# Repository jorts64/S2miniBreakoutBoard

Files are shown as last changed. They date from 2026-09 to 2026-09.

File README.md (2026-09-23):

# S2miniBreakoutBoard
Breakout Board for Lolin S2 mini from wemos.cc

You can 3D print [this STL](STL/soldarS2miniBreakout.stl) for easy soldering. 

I2C slave firmware included with examples of master code in Arduino and micropython

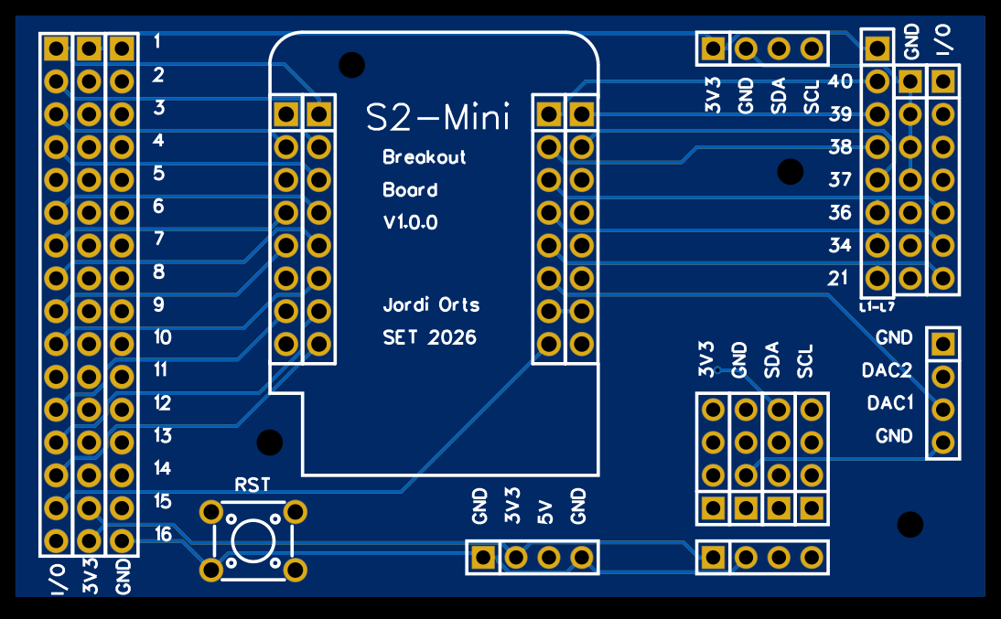
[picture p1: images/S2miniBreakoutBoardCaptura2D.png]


* Easy access to all exposed pins of the S2 mini
* I2C bus connector

## Standalone mode

You can use this PCB as a S2-mini breakout for development or project core. Some [micropython examples](standalone/micropython) included.

In this mode you can put a 7xLED VCC COM module for easy development. Or a 8xLED module (with one pin in the air) as shown in picture:

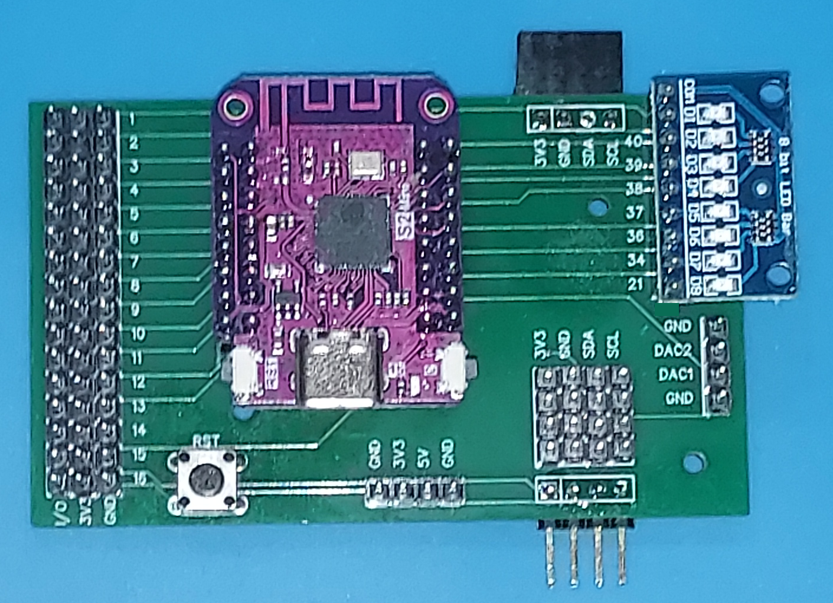
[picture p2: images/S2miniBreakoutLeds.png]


## Slave mode

* Arduino firmware. [Micropython](I2Cslave/master/micropython/ejemplo.py) and [Arduino](https://github.com/jorts64/S2MiniSlave/blob/main/examples/Basic/Basic.ino) master examples avalaible.
* [Arduino library](https://github.com/jorts64/S2MiniSlave)
* 16 I/O you can set individually as INPUT, INPUT_PULLUP, OUTPUT, PWM or ADC
* 2 DAC outputs
* I2C address by jumper configuration, you can choose any I2C address. You can chain up to 128 S2 mini I2C slave devices, if you ignore protocol restrictions [i2c address list: the 0x00–0x77 map](https://i2c.net/i2c-addresses/), so you could get 2048 configurable GPIO and 256 DAC inputs !!
* Really cheap device, about $10 S2 mini included. You can order PCB from JLCPCB and buy electronic components at Aliexpress.

In this mode you must set I2C address with jumpers to GND (active LOW) in pins 21, 34, 36, 37, 38, 39 & 40 (MSB...LSB). The slave in picture has I2C address 0x60:

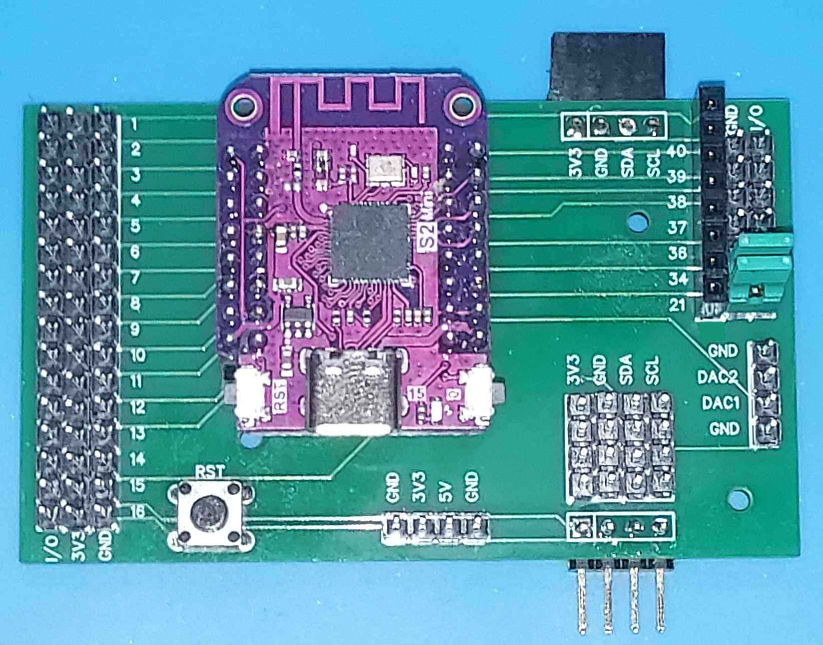
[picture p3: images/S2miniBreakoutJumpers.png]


Female and Male right angle connectors at the top and bottom of the PCB lets chain our S2 mini slaves in the I2C bus.

## Hardware restricctions

As this board uses S2 mini microcontroller:

* DAC2 will give you error voltages because it's connected internally with a 10k pullup. You can improve the output with a R load [ESP32-S2 DAC2 Requires Load Resistor? ](https://github.com/espressif/arduino-esp32/issues/9324?utm_source=chatgpt.com)
* PWM are limited to 8 GPIO.
* ADC witn GPIO15 will give bad results. This GPIO is internally connected to the LED builtiin.
* ADC 11-16 don't be avalaible if WiFi is enabled. Neither DAC1 and DAC2. But they still can be used as INPUT, INPUT_PULLUP, OUTPUT or PWM with WiFi enabled.

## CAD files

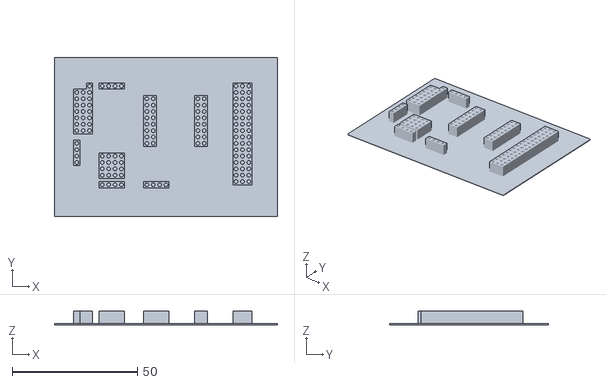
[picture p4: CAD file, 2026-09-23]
STL/soldarS2miniBreakout.stl
88.9 x 63.5 x 5.60

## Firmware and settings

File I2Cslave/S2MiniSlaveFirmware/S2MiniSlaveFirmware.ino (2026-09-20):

#include <Arduino.h>
#include <Wire.h>

// ============================================================
// S2 Mini I2C Slave
// ============================================================
//
// ESP32-S2 / LOLIN S2 Mini
//
// I2C:
//   SDA = GPIO33
//   SCL = GPIO35
//
// Address:
//   GPIO21 = bit 6 (MSB)
//   GPIO34 = bit 5
//   GPIO36 = bit 4
//   GPIO37 = bit 3
//   GPIO38 = bit 2
//   GPIO39 = bit 1
//   GPIO40 = bit 0 (LSB)
//
// GPIO 1..16:
//   INPUT
//   INPUT_PULLUP
//   OUTPUT
//   PWM
//   ADC
//
// DAC:
//   DAC1 = GPIO17
//   DAC2 = GPIO18
//
// ============================================================


// ------------------------------------------------------------
// I2C
// ------------------------------------------------------------

#define I2C_SDA_PIN       33
#define I2C_SCL_PIN       35

// ------------------------------------------------------------
// Address configuration pins
// ------------------------------------------------------------

#define ADDR_BIT6_PIN     21
#define ADDR_BIT5_PIN     34
#define ADDR_BIT4_PIN     36
#define ADDR_BIT3_PIN     37
#define ADDR_BIT2_PIN     38
#define ADDR_BIT1_PIN     39
#define ADDR_BIT0_PIN     40

// ------------------------------------------------------------
// Controlled GPIOs
// ------------------------------------------------------------

#define FIRST_IO          1
#define LAST_IO           16
#define NUM_IO            16

// ------------------------------------------------------------
// DAC
// ------------------------------------------------------------

#define DAC1_PIN          17
#define DAC2_PIN          18

// ------------------------------------------------------------
// PWM
//
// ESP32-S2 has 8 LEDC channels.
// 12-bit PWM is used internally.
//
// The register exposed to the master is 16-bit:
//   0     = 0%
//   65535 = 100%
//
// It is converted to the 12-bit hardware range.
// ------------------------------------------------------------

#define PWM_FREQUENCY     5000
#define PWM_RESOLUTION    12
#define PWM_MAX           ((1UL << PWM_RESOLUTION) - 1)

// ESP32-S2 dispone de 8 canales LEDC
#define MAX_PWM_CHANNELS  8

// Número de GPIO que actualmente utilizan PWM
uint8_t activePWMChannels = 0;

// Estado de cada GPIO
bool pwmAttached[NUM_IO];

// ------------------------------------------------------------
// Protocol
// ------------------------------------------------------------

#define PROTOCOL_VERSION  1

#define REG_VERSION       0x00
#define REG_ADDRESS       0x01
#define REG_PWM_CHANNELS  0x02

#define REG_INPUTS        0x10
#define REG_OUTPUTS       0x12

#define REG_MODE_BASE     0x20
#define REG_PWM_BASE      0x40
#define REG_ADC_BASE      0x60

#define REG_DAC1          0x80
#define REG_DAC2          0x82


// ------------------------------------------------------------
// Pin modes
// ------------------------------------------------------------

enum PinModeS2 : uint8_t
{
  MODE_INPUT = 0,
  MODE_INPUT_PULLUP = 1,
  MODE_OUTPUT = 2,
  MODE_PWM = 3,
  MODE_ADC = 4
};


// ------------------------------------------------------------
// Global state
// ------------------------------------------------------------

// Configuration of GPIO1..16
volatile uint8_t pinModes[NUM_IO];

// Digital input register
volatile uint16_t inputRegister = 0;

// Digital output register
volatile uint16_t outputRegister = 0;

// PWM registers
volatile uint16_t pwmRegisters[NUM_IO];

// ADC registers
volatile uint16_t adcRegisters[NUM_IO];

// DAC registers
volatile uint16_t dac1Register = 0;
volatile uint16_t dac2Register = 0;

// I2C register pointer
volatile uint8_t registerPointer = 0;


// ------------------------------------------------------------
// Synchronization
// ------------------------------------------------------------

portMUX_TYPE dataMux = portMUX_INITIALIZER_UNLOCKED;


// ------------------------------------------------------------
// Calculate I2C address
// ------------------------------------------------------------

uint8_t readI2CAddress()
{
  uint8_t address = 0;

  if (digitalRead(ADDR_BIT6_PIN) == LOW)
    address |= 0x40;

  if (digitalRead(ADDR_BIT5_PIN) == LOW)
    address |= 0x20;

  if (digitalRead(ADDR_BIT4_PIN) == LOW)
    address |= 0x10;

  if (digitalRead(ADDR_BIT3_PIN) == LOW)
    address |= 0x08;

  if (digitalRead(ADDR_BIT2_PIN) == LOW)
    address |= 0x04;

  if (digitalRead(ADDR_BIT1_PIN) == LOW)
    address |= 0x02;

  if (digitalRead(ADDR_BIT0_PIN) == LOW)
    address |= 0x01;

  return address;
}


// ------------------------------------------------------------
// Read 16-bit value from register
// ------------------------------------------------------------

uint16_t getRegister16(uint8_t reg)
{
  switch (reg)
  {
    case REG_INPUTS:
      return inputRegister;

    case REG_OUTPUTS:
      return outputRegister;

    case REG_DAC1:
      return dac1Register;

    case REG_DAC2:
      return dac2Register;

    default:
      break;
  }

  // PWM registers
  if (reg >= REG_PWM_BASE &&
      reg < REG_PWM_BASE + NUM_IO * 2)
  {
    uint8_t index = (reg - REG_PWM_BASE) / 2;
    return pwmRegisters[index];
  }

  // ADC registers
  if (reg >= REG_ADC_BASE &&
      reg < REG_ADC_BASE + NUM_IO * 2)
  {
    uint8_t index = (reg - REG_ADC_BASE) / 2;
    return adcRegisters[index];
  }

  return 0;
}


// ------------------------------------------------------------
// Write 16-bit value to register
// ------------------------------------------------------------

void setRegister16(uint8_t reg, uint16_t value)
{
  switch (reg)
  {
    case REG_OUTPUTS:
      outputRegister = value;
      return;

    case REG_DAC1:
      dac1Register = value;
      return;

    case REG_DAC2:
      dac2Register = value;
      return;

    default:
      break;
  }

  // PWM
  if (reg >= REG_PWM_BASE &&
      reg < REG_PWM_BASE + NUM_IO * 2)
  {
    uint8_t index = (reg - REG_PWM_BASE) / 2;
    pwmRegisters[index] = value;
    return;
  }
}


// ------------------------------------------------------------
// Configure one GPIO
// ------------------------------------------------------------

void configurePin(uint8_t index, uint8_t mode)
{
  if (index >= NUM_IO)
    return;

  uint8_t pin = FIRST_IO + index;

  // ----------------------------------------------------------
  // Si estaba funcionando como PWM y cambia de modo,
  // liberar el canal LEDC.
  // ----------------------------------------------------------

  if (pwmAttached[index] && mode != MODE_PWM)
  {
    ledcDetach(pin);

    pwmAttached[index] = false;

    if (activePWMChannels > 0)
      activePWMChannels--;
  }


  // ----------------------------------------------------------
  // Configuración del nuevo modo
  // ----------------------------------------------------------

  switch (mode)
  {
    case MODE_INPUT:

      pinMode(pin, INPUT);

      break;


    case MODE_INPUT_PULLUP:

      pinMode(pin, INPUT_PULLUP);

      break;


    case MODE_OUTPUT:

      pinMode(pin, OUTPUT);

      break;


    case MODE_PWM:

      // ------------------------------------------------------
      // Comprobar que todavía queda un canal LEDC disponible.
      // ------------------------------------------------------

      if (!pwmAttached[index])
      {
        if (activePWMChannels >= MAX_PWM_CHANNELS)
        {
          // No quedan canales PWM.
          //
          // No cambiamos el modo del pin.
          // Lo dejamos como INPUT para tener un estado
          // conocido.

          pinMode(pin, INPUT);

          pinModes[index] = MODE_INPUT;

          return;
        }


        // ----------------------------------------------------
        // Asignar automáticamente un canal LEDC al GPIO.
        // ----------------------------------------------------

        if (ledcAttach(
              pin,
              PWM_FREQUENCY,
              PWM_RESOLUTION))
        {
          pwmAttached[index] = true;

          activePWMChannels++;
        }
        else
        {
          // Error al asignar LEDC.

          pinMode(pin, INPUT);

          pinModes[index] = MODE_INPUT;

          return;
        }
      }

      break;


    case MODE_ADC:

      // ADC utiliza el GPIO como entrada.
      pinMode(pin, INPUT);

      break;


    default:

      mode = MODE_INPUT;

      pinMode(pin, INPUT);

      break;
  }


  pinModes[index] = mode;
}

// ------------------------------------------------------------
// Update PWM outputs
// ------------------------------------------------------------

void updatePWM()
{
  for (uint8_t i = 0; i < NUM_IO; i++)
  {
    // Sólo actualizamos GPIO configurados como PWM
    // y que realmente tengan un canal LEDC asignado.

    if (pinModes[i] != MODE_PWM)
      continue;

    if (!pwmAttached[i])
      continue;


    uint8_t pin = FIRST_IO + i;


    // --------------------------------------------------------
    // Registro de 16 bits:
    //
    // 0      = 0 %
    // 65535  = 100 %
    //
    // Convertir a la resolución LEDC de 12 bits.
    // --------------------------------------------------------

    uint16_t value =
      pwmRegisters[i];


    uint32_t duty =
      ((uint32_t)value * PWM_MAX) / 65535UL;


    // --------------------------------------------------------
    // IMPORTANTE:
    //
    // ledcWrite() recibe el GPIO, no el número de canal.
    // --------------------------------------------------------

    ledcWrite(
      pin,
      duty
    );
  }
}


// ------------------------------------------------------------
// Update digital outputs
// ------------------------------------------------------------

void updateOutputs()
{
  uint16_t value = outputRegister;

  for (uint8_t i = 0; i < NUM_IO; i++)
  {
    if (pinModes[i] != MODE_OUTPUT)
      continue;

    uint8_t pin = FIRST_IO + i;

    bool state = value & (1U << i);

    digitalWrite(pin, state ? HIGH : LOW);
  }
}


// ------------------------------------------------------------
// Read digital inputs
// ------------------------------------------------------------

void updateInputs()
{
  uint16_t value = 0;

  for (uint8_t i = 0; i < NUM_IO; i++)
  {
    if (pinModes[i] != MODE_INPUT &&
        pinModes[i] != MODE_INPUT_PULLUP)
    {
      continue;
    }

    uint8_t pin = FIRST_IO + i;

    if (digitalRead(pin))
      value |= (1U << i);
  }

  inputRegister = value;
}


// ------------------------------------------------------------
// Read ADC inputs
// ------------------------------------------------------------

void updateADC()
{
  for (uint8_t i = 0; i < NUM_IO; i++)
  {
    if (pinModes[i] != MODE_ADC)
      continue;

    uint8_t pin = FIRST_IO + i;

    int value = analogRead(pin);

    if (value < 0)
      value = 0;

    if (value > 4095)
      value = 4095;

    adcRegisters[i] = (uint16_t)value;
  }
}


// ------------------------------------------------------------
// Update DAC outputs
// ------------------------------------------------------------

void updateDAC()
{
  // ESP32-S2 DAC resolution = 8 bits.
  //
  // Master writes 0..65535.
  // Hardware receives 0..255.

  uint8_t dac1 =
    ((uint32_t)dac1Register * 255UL) / 65535UL;

  uint8_t dac2 =
    ((uint32_t)dac2Register * 255UL) / 65535UL;

  dacWrite(DAC1_PIN, dac1);
  dacWrite(DAC2_PIN, dac2);
}


// ------------------------------------------------------------
// I2C RECEIVE
// ------------------------------------------------------------
//
// Master writes:
//
//   [REGISTER]
//
// or:
//
//   [REGISTER][DATA...]
//
// If only REGISTER is received, it becomes the register
// pointer for a subsequent I2C read.
//
// ------------------------------------------------------------

void onI2CReceive(int count)
{
  if (count <= 0)
    return;

  uint8_t reg = Wire.read();

  registerPointer = reg;

  // No data: only change register pointer
  if (count == 1)
    return;

  // Configuration registers
  if (reg >= REG_MODE_BASE &&
      reg < REG_MODE_BASE + NUM_IO)
  {
    uint8_t mode = Wire.read();

    configurePin(
      reg - REG_MODE_BASE,
      mode
    );

    return;
  }

  // 16-bit registers
  if (count >= 3)
  {
    uint8_t msb = Wire.read();
    uint8_t lsb = Wire.read();

    uint16_t value =
      ((uint16_t)msb << 8) | lsb;

    setRegister16(reg, value);
  }
}


// ------------------------------------------------------------
// I2C REQUEST
// ------------------------------------------------------------

void onI2CRequest()
{
  uint8_t reg = registerPointer;

  switch (reg)
  {
    case REG_VERSION:

      Wire.write(PROTOCOL_VERSION);
      return;

    case REG_ADDRESS:

      // The address is fixed after boot.
      Wire.write(readI2CAddress());
      return;

    case REG_PWM_CHANNELS:

      Wire.write(8);
      return;

    default:
      break;
  }

  // Configuration registers
  if (reg >= REG_MODE_BASE &&
      reg < REG_MODE_BASE + NUM_IO)
  {
    Wire.write(
      pinModes[reg - REG_MODE_BASE]
    );

    return;
  }

  // 16-bit registers
  uint16_t value = getRegister16(reg);

  Wire.write((uint8_t)(value >> 8));
  Wire.write((uint8_t)(value & 0xFF));
}


// ------------------------------------------------------------
// SETUP
// ------------------------------------------------------------

void setup()
{
  Serial.begin(115200);

  delay(20);

  // ----------------------------------------------------------
  // Address pins
  // ----------------------------------------------------------

  pinMode(ADDR_BIT6_PIN, INPUT_PULLUP);
  pinMode(ADDR_BIT5_PIN, INPUT_PULLUP);
  pinMode(ADDR_BIT4_PIN, INPUT_PULLUP);
  pinMode(ADDR_BIT3_PIN, INPUT_PULLUP);
  pinMode(ADDR_BIT2_PIN, INPUT_PULLUP);
  pinMode(ADDR_BIT1_PIN, INPUT_PULLUP);
  pinMode(ADDR_BIT0_PIN, INPUT_PULLUP);

  // Address is sampled once after reset.
  uint8_t address = readI2CAddress();

  Serial.print("I2C address: 0x");

  if (address < 16)
    Serial.print("0");

  Serial.println(address, HEX);

  // ----------------------------------------------------------
  // Initialize controlled GPIOs
  // ----------------------------------------------------------

  for (uint8_t i = 0; i < NUM_IO; i++)
  {
    pinModes[i] = MODE_INPUT;
    pwmRegisters[i] = 0;
    adcRegisters[i] = 0;

    pinMode(
      FIRST_IO + i,
      INPUT
    );
  }
  
  // ----------------------------------------------------------
  // PWM
  // ----------------------------------------------------------


  for (uint8_t i = 0; i < NUM_IO; i++)
  {
    pinModes[i] = MODE_INPUT;
    pwmRegisters[i] = 0;
    adcRegisters[i] = 0;
    pwmAttached[i] = false;
    pinMode(
      FIRST_IO + i,
      INPUT
    );
  }
  activePWMChannels = 0;
  

  // ----------------------------------------------------------
  // DAC
  // ----------------------------------------------------------

  dac1Register = 0;
  dac2Register = 0;

  dacWrite(DAC1_PIN, 0);
  dacWrite(DAC2_PIN, 0);

  // ----------------------------------------------------------
  // I2C slave
  // ----------------------------------------------------------

  Wire.onReceive(onI2CReceive);
  Wire.onRequest(onI2CRequest);

  if (!Wire.begin(
        address,
        I2C_SDA_PIN,
        I2C_SCL_PIN,
        100000))
  {
    Serial.println("ERROR: I2C slave initialization failed");
    while (true)
      delay(1000);
  }

  Serial.println("S2MiniSlave ready");
}


// ------------------------------------------------------------
// LOOP
// ------------------------------------------------------------

void loop()
{
  // The registers are synchronized with the physical
  // inputs and outputs on every loop iteration.

  updateInputs();
  updateADC();
  updateOutputs();
  updatePWM();
  updateDAC();

  delay(1);
}

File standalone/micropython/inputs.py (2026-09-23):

from machine import Pin
import time

pines = [21, 34, 36, 37, 38, 39, 40]

# Sin pull_up
# entradas = [Pin(pin, Pin.IN) for pin in pines]
# Configurar entradas con pull-up interno
entradas = [Pin(pin, Pin.IN, Pin.PULL_UP) for pin in pines]

while True:
    valores = [entrada.value() for entrada in entradas]

    print(
        "GPIO21:", valores[0],
        "GPIO34:", valores[1],
        "GPIO36:", valores[2],
        "GPIO37:", valores[3],
        "GPIO38:", valores[4],
        "GPIO39:", valores[5],
        "GPIO40:", valores[6]
    )

    time.sleep(1)

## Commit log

2026-09-23 read I2C fix
    [soldarS2miniBreakout.stl]
2026-09-23 Added PCB pictures
